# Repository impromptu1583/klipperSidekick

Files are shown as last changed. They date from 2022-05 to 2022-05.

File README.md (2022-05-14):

# KlipperSidekick
Klipper config and macros for use with the Lulzbot sidekick

# WARNING
This is very much a work-in-progress config. Use at your own risk and please be safe.
Also, please review [Issue #1](https://github.com/mcmillanje/klipperSidekick/issues/1).

## Firmware flashing
Follow the flashing instructions in [Klipper's Documentation](https://www.klipper3d.org/Installation.html)

Choose `Atmega AVR` as the architecture and `atmega2560` as the processor model on the menuconfig section.


Follow the instructions closely and if you receive any timeout messages power the printer off and back on again then retry.

## configuration

### printer.cfg
#### homing
Edit printer.config and uncomment the homing option of your choice:
1. low_current_home
z stepper current will be reduced to 15% then move down 10mm, then full current back up 10mm
If nozzle is correctly parked this will result in a quick down-up move pre-homing
If nozzle is resting on bed it won't be able to move down due to low current then will move up (to clear bed for xy home)
this is still bad for your printer and should be avoided (always park the nozzle) but it's better than nothing and doesn't require hardware mod
z_stop_home (WIP)
2. this will require the addition of a physical z endstop (I will make documentation). The homing macro will verify the gantry is properly parked before homing and either notify user or try to park itself if not. This will provide a fast and safe homing and would be the recommended method!
danger_home
3. This will provide a fast homing that skips the failsafes & assumes gantry is parked. If gantry isn't parked it will slam against the bed and likely cause damage. Don't use unless you're 100% always going to park your gantry no matter what!

#### toolhead
Uncomment the toolhead you're using. You can make multiple toolhead files for different configurations and easily switch this way.

#### filament runout sensor
Comment / Uncomment the filament runout sensor section of settings.cfg depending on if you have this upgrade installed

TODO: 
z probe
pid Tuning

## slicer config (Superslicer / Prusaslicer)
My slicer of choice is Superslicer is a fork of Prusaslicer that has a built-in klipper preset.

For either Superslicer or Prusaslicer add these custom gcode commands in the printer settings tab:

Replace start gcode with:
```
START_PRINT BED_TEMP=[bed_temperature] EXTRUDER_TEMP=[first_layer_temperature]
```
Replace end gcode with:
```
END_PRINT
```

You may also need to check `Only custom Start G-code`.

## slicer config (CURA)
Macros contains a START_PRINT and END_PRINT macro
Replace start gcode with:
```
START_PRINT BED_TEMP={material_bed_temperature_layer_0} EXTRUDER_TEMP={material_print_temperature_layer_0}
```
Replace end gcode with:
```
END_PRINT
```

## reference material
### hardware
Schematic: https://github.com/ultimachine/EinsyRetro/blob/1.0b/board/Project%20Outputs%20for%20EinsyRetro/Schematic%20Prints_EinsyRetro_1.0b.PDF
OHAI: https://ohai.lulzbot.com/group/taz-sidekick-289/

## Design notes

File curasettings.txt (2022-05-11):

CURA Gcode start/end

START_PRINT BED_TEMP={material_bed_temperature_layer_0} EXTRUDER_TEMP={material_print_temperature_layer_0}

END_PRINT

Start Gcode:

M109 R{material_soften_temperature} ; soften filament before homing Z
G28 ; Home all axis
G1 E-15 F100 ; retract filament
M140 S{material_bed_temperature_layer_0}     	; start bed heating up
M104 S{material_probe_temperature}     	        ; start extruder heating to probe temp
M190 S{material_bed_temperature_layer_0}     	; wait for bed to reach printing temp
G29     					; start auto leveling
G0 X0 Y0 F5000
M109 R{material_print_temperature_layer_0}     	; wait for extruder to reach initial printing temp
M117 SideKick Printing...   ; progress indicator message on LCD
G1 Z2 E0 F75 ; prime tiny bit of filament into the nozzle

### new
G28 ; Home all axis
BED_MESH_CALIBRATE ; auto bed level
M140 S{material_bed_temperature_layer_0}     	; start bed heating up
M104 S{material_print_temperature_layer_0}  	; start extruder heating to probe temp
G0 X0 Y0 z1 F5000 ; move to origin
M190 S{material_bed_temperature_layer_0}     	; wait for bed to reach printing temp
M109 R{material_print_temperature_layer_0}     	; wait for extruder to reach initial printing temp
G1 Z2 E0 F75 ; prime tiny bit of filament into the nozzle

End Gcode 
;This G-Code has been generated specifically for the LulzBot Sidekick with a Universal Tool Head
M400                                      ; wait for moves to finish
M140 S{material_part_removal_temperature} ; start bed cooling
M104 S0                                   ; disable hotend
M107                                      ; disable fans
G92 E5                                    ; set extruder to 5mm for retract on print end
M117 Cooling please wait                  ; progress indicator message on LCD
G1 Y-10 Z185 E0 F3000                     ; move to cooling position
G1 E5                                     ; re-prime extruder
M190 R{material_part_removal_temperature} ; wait for bed to cool down to removal temp
G27                                       ; present finished print
M140 S{material_keep_part_removal_temperature_t}; keep temperature or cool down
M77					                      ; End GLCD Print Timer
G90                                       ; absolute positioning
M18 X E				  	                  ; turn off x and e axis
M117 Print Complete.                      ; print complete message

### new
G0 Y0 Z184 E0 F3000 ; park gantry at zmax
M400
TURN_OFF_HEATERS
M107 ; disable fans
M18

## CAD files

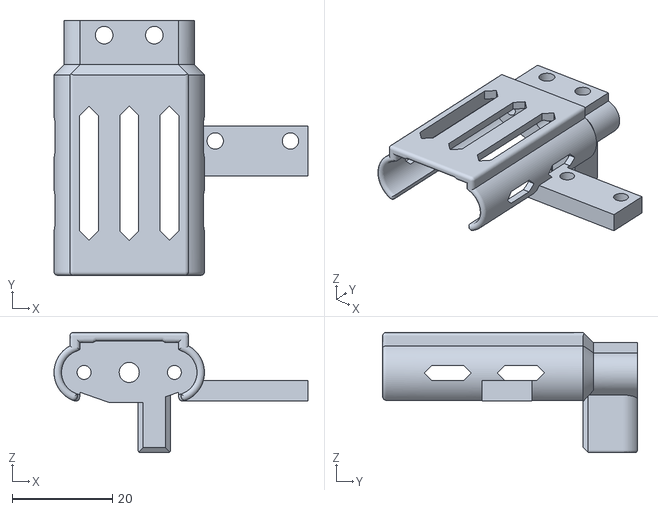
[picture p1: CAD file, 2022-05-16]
stl/x_bltouch_mount.stl
50.6 x 50.8 x 24.0

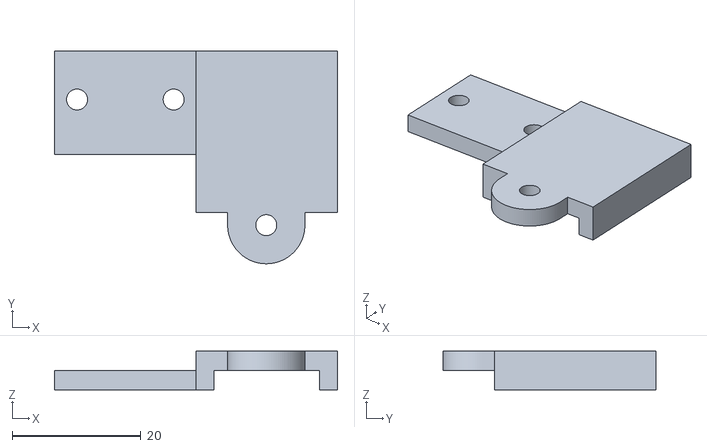
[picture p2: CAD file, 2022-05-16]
stl/y_bed_shelf.stl
43.9 x 33.0 x 6.00

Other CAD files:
f3d/sidekick289_accelmounts.f3d

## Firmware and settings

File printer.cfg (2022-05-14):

######################################################################
# Configuration
######################################################################


###### includes ######
[include mainsail.cfg]
[include macros.cfg]
[include settings.cfg]

[respond]

#Prevents communication issues with SPI drivers
[static_digital_output disable_sdcard]
pins: PB0

[stepper_x]
step_pin: PC0 
dir_pin: !PL0
enable_pin: !PA7
microsteps: 64
rotation_distance: 32
homing_speed:50
homing_retract_dist:0
#endstop_pin: ^PB6
endstop_pin: tmc2130_stepper_x:virtual_endstop
position_endstop: -5.5
position_max: 164
position_min: -5.5

[tmc2130 stepper_x]
cs_pin: PG0
run_current: .5
sense_resistor: 0.220
diag1_pin: !PK2
driver_SGT: 3 # -64 is most sensitive value, 63 is least sensitive

[stepper_y]
step_pin: PC1
dir_pin: !PL1
enable_pin: !PA6
microsteps: 64
rotation_distance: 32
homing_speed:16
#endstop_pin: ^PB5
endstop_pin: tmc2130_stepper_y:virtual_endstop
position_endstop: -34
position_max: 168
position_min: -34
homing_speed:50
homing_retract_dist:0

[tmc2130 stepper_y]
cs_pin: PG2
run_current: .5
sense_resistor: 0.220
diag1_pin: !PK7
driver_SGT: 3 # -64 is most sensitive value, 63 is least sensitive

[stepper_z]
step_pin: PC2
dir_pin: !PL2
enable_pin: !PA5
microsteps: 64
rotation_distance: 32
#endstop_pin: ^PB4
#endstop_pin: tmc2130_stepper_z:virtual_endstop
endstop_pin: probe:z_virtual_endstop
#position_endstop: 0.5
#position_max: 260
position_max: 400
position_min: -10

[tmc2130 stepper_z]
cs_pin: PK5
run_current: .5
sense_resistor: 0.220
diag1_pin: !PK6

[tmc2130 extruder]
cs_pin: PK4
run_current: .5
sense_resistor: 0.220
diag1_pin: !PK3

# Send: M906
# Recv: X driver current: 975
# Recv: Y driver current: 975
# Recv: Z driver current: 975
# Recv: E driver current: 960
# Recv: ok P15 B3

[heater_bed]
heater_pin: PG5
sensor_type: Honeywell 100K 135-104LAG-J01
sensor_pin: PF2
control: pid
pid_Kp: 51.649
pid_Ki: 0.471
pid_Kd: 1415.841
min_temp: 0
max_temp: 100

[fan]
pin: PH5

# nozzle fan is plugged in to PD4 / XMIN and isn't PWM controlled
# not sure how to control this. By default on all the time which is fine
# would be nice to allow it to reduce speed though
#[heater_fan nozzle_cooling_fan]
#pin: PD4
#heater: extruder



[output_pin stepper_xy_current]
#define MOTOR_CURRENT_PWM_XY_PIN 46
pin: PL3
pwm: True
scale: 2.0
cycle_time: .000030
hardware_pwm: True
static_value: 1.300

[output_pin stepper_z_current]
pin: PL4
pwm: True
scale: 2.0
cycle_time: .000030
hardware_pwm: True
static_value: 1.630

[output_pin stepper_e_current]
pin: PL5
pwm: True
scale: 2.0
cycle_time: .000030
hardware_pwm: True
static_value: 1.250

[mcu]
serial: /dev/ttyACM0

[printer]
kinematics: cartesian
max_velocity: 300
max_accel: 2000
#max_z_velocity: 7
max_z_accel: 500

[bltouch]
sensor_pin: ^PB5
control_pin: PB4
x_offset: -1
y_offset: 50
z_offset: 1.58
speed: 50

[bed_mesh]
speed: 100
horizontal_move_z: 5
mesh_min: 20, 20
mesh_max: 140, 140
probe_count: 3, 3

[display]
lcd_type: st7920
cs_pin:PD5 #D16
sclk_pin:PD2 #RX1#D23
sid_pin:PD3 #TX1#D17
encoder_pins:^PJ2,^PJ1 #PJ2, TX3#^D31, ^D33 
click_pin: ^!PH6 #^!D35

[gcode_arcs]
resolution: 0.5

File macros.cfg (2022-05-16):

######################################################################
# Park Nozzle / gantry 
######################################################################

[gcode_macro PARK]
gcode:
    g90
    g1 x80 y80 z160 f8000
    g1 x80 y80 z182.5 f2000

######################################################################
# Start Print and End Print
######################################################################

# Replace the slicer's custom start and end g-code scripts with
# START_PRINT and END_PRINT.

[gcode_macro START_PRINT]
gcode:
    {% set BED_TEMP = params.BED_TEMP|default(60)|float %}
    {% set EXTRUDER_TEMP = params.EXTRUDER_TEMP|default(210)|float %}
    # Start bed heating
    M140 S{BED_TEMP}
    # Use absolute coordinates
    G90
    # Reset the G-Code Z offset (adjust Z offset if needed)
    SET_GCODE_OFFSET Z=0.0
    # Home the printer
    {% if printer.toolhead.homed_axes != "xyz" %}
        G28
    {% endif %}
    
    # Auto Bed Level
    BED_MESH_CALIBRATE
    
    # start bed and extruder heading up
    M140 S{BED_TEMP}
    M104 S{EXTRUDER_TEMP}    
    # Move the nozzle to origin
    G1 X0 Y0 Z5 F3000

    # Wait for bed to reach temperature
    #M190 S{BED_TEMP}
    TEMPERATURE_WAIT sensor=heater_bed minimum={BED_TEMP}
    m118 bed temp reached
    # Set and wait for nozzle to reach temperature
    #M109 S{EXTRUDER_TEMP}
    TEMPERATURE_WAIT sensor=extruder minimum={EXTRUDER_TEMP}
    m118 extruder temp reached
    # lower to wipe
    G1 Z0.15 F300
    M83
    G1 Z2 E1 F75 ; prime tiny bit of filament into the nozzle
    M82
    
[gcode_macro mario]
gcode:
    M300 S1046 P150
    M300 S1318 P150
    M300 S1567 P150
    M300 S2093 P150
    M300 S2637 P150
    M300 S3135 P400
    M300 S2637 P400
    M300 S1046 P150
    M300 S1244 P150
    M300 S1661 P150
    M300 S2093 P150
    M300 S2489 P150
    M300 S3322 P400
    M300 S2489 P400
    M300 S1174 P150
    M300 S1396 P150
    M300 S932 P150
    M300 S2349 P150
    M300 S2793 P150
    M300 S1864 P150
    M300 S0 P400
    M300 S1864 P120
    M300 S0 P60
    M300 S1864 P120
    M300 S0 P60
    M300 S1864 P120
    M300 S0 P60
    M300 S4186 P900 ;Congrats    
    
[gcode_macro END_PRINT]
gcode:
    # Turn off bed, extruder, and fan
    M140 S0
    M104 S0
    M106 S0
    # Move nozzle away from print while retracting
    G91
    G1 X-2 Y-2 E-3 F300
    G90
    M83
    # Park the nozzle, present the bed
    g1 x80 y161 z184 f6000
    M400 # finish any moves
    # Disable steppers
    M84

[gcode_macro M300]
gcode:
    # Use a default 1kHz tone if S is omitted.
    {% set S = params.S|default(1000)|int %}
    # Use a 10ms duration is P is omitted.
    {% set P = params.P|default(100)|int %}
    SET_PIN PIN=BEEPER_pin VALUE=0.5 CYCLE_TIME={ 1.0/S if S > 0 else 1 }
    G4 P{P}
    SET_PIN PIN=BEEPER_pin VALUE=0


######################################################################
# Filament Change
######################################################################

# M600: Filament Change. This macro will pause the printer, move the
# tool to the change position, and retract the filament 50mm. Adjust
# the retraction settings for your own extruder. After filament has
# been changed, the print can be resumed from its previous position
# with the "RESUME" gcode.

[pause_resume]

[gcode_macro M600]
gcode:
    {% set X = params.X|default(10)|float %}
    {% set Y = params.Y|default(10)|float %}
    {% set Z = params.Z|default(40)|float %}
    SAVE_GCODE_STATE NAME=M600_state
    PAUSE
    G91
    G1 E-.8 F2700
    G1 Z{Z}
    G90
    G1 X{X} Y{Y} F3000
    G91
    G1 E-100 F1000
    RESTORE_GCODE_STATE NAME=M600_state

######################################################################
# Beeper
######################################################################

# M300 : Play tone. Beeper support, as commonly found on usual LCD
# displays (i.e. RepRapDiscount 2004 Smart Controller, RepRapDiscount
# 12864 Full Graphic). This defines a custom I/O pin and a custom
# GCODE macro.  Usage:
#   M300 [P<ms>] [S<Hz>]
#   P is the tone duration, S the tone frequency.
# The frequency won't be pitch perfect.

[output_pin BEEPER_pin]
pin: PH2
#   Beeper pin. This parameter must be provided.
pwm: True
#   A piezo beeper needs a PWM signal, a DC buzzer doesn't.
value: 0
#   Silent at power on, set to 1 if active low.
shutdown_value: 0
#   Disable at emergency shutdown (no PWM would be available anyway).
cycle_time: 0.001
#   Default PWM frequency : 0.001 = 1ms will give a tone of 1kHz
#   Although not pitch perfect.

[gcode_macro M300]
gcode:
    # Use a default 1kHz tone if S is omitted.
    {% set S = params.S|default(1000)|int %}
    # Use a 10ms duration is P is omitted.
    {% set P = params.P|default(100)|int %}
    SET_PIN PIN=BEEPER_pin VALUE=0.5 CYCLE_TIME={ 1.0/S if S > 0 else 1 }
    G4 P{P}
    SET_PIN PIN=BEEPER_pin VALUE=0
    
######################################################################
# Tool to find gcode vars
######################################################################  

[gcode_macro SEARCH_VARS]
gcode:
    {% set search = params.S|lower %}
    {% set ns = namespace() %}
    {% for item in printer  %}
        {% if ' ' in item %}
            {% set ns.path = ['printer', "['%s']" % (item), ''] %}
        {% else %}
            {% set ns.path = ['printer.', item, ''] %}   
        {% endif %} 

        {% if search in ns.path|lower %}
            { action_respond_info(ns.path|join) }
        {% endif %} 

        {% if printer[item].items() %}
            {% for childkey, child in printer[item].items() recursive %}
                {% set ns.path = ns.path[:loop.depth|int + 1] %}

                {% if ' ' in childkey %}
                    {% set null = ns.path.append("['%s']" % (childkey)) %}
                {% else %}
                    {% set null = ns.path.append(".%s" % (childkey)) %}
                {% endif %} 

                {% if child is mapping  %}
                    { loop(child.items()) }
                {% else %}
                    {% if search in ns.path|lower %}
                        { action_respond_info("%s : %s" % (ns.path|join, child)) }   
                    {% endif %} 
                {% endif %} 
                
            {% endfor %}
        {% endif %} 
    {% endfor %}

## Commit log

2022-05-10 initial upload of WIP config files
    [289.cfg, e_m175.cfg]
2022-05-10 added macro file
    [289.cfg, macros.cfg]
2022-05-10 good initial config
    [289.cfg, macros.cfg]
2022-05-11 z offset changes & removed extra macros
    [289.cfg, macros.cfg]
2022-05-11 fixed end code and tweaked PA value
    [e_m175.cfg, macros.cfg]
2022-05-12 update
    changed microsteps and homing
    using custom homing macro instead of safe_z_home
    [289.cfg, homing.cfg]
2022-05-12 Display + Beeper (M300) implementation
    [289.cfg, macros.cfg]
2022-05-12 new homing options
    [289.cfg, danger_home.cfg, homing.cfg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]
2022-05-12 updated homing options
    [danger_home.cfg, low_current_home.cfg]
2022-05-12 changed filename
    [289.cfg, printer.cfg]
2022-05-12 documentation updates
    [macros.cfg]
2022-05-12 Initial runout sensor config
    [printer.cfg]
2022-05-12 runout sensor tested working
    [printer.cfg]
2022-05-12 breaking out settings files
    [filamentSensor.cfg, printer.cfg, settings.cfg]
2022-05-12 further breakout of settings
    [printer.cfg, settings.cfg]
2022-05-13 arc welding + m83 for relative extrusion
    [macros.cfg, printer.cfg]
2022-05-14 big update
    added limit switch safe z as well as a mount stl
    [e_m175.cfg, limitswitch_mount.stl, macros.cfg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]
2022-05-16 z homing fix
    Z now homes to zmax - no additional hardware required and always safe!
    [bltouch+x_accel_mount.stl, danger_home.cfg, e_m175.cfg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]
2022-05-16 Update macros.cfg
    m600 and comments
    [macros.cfg]
2022-05-16 updated stls
    [accelmount v2.f3d, limitswitch_mount.stl, sidekick289_accelmounts.f3d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]
